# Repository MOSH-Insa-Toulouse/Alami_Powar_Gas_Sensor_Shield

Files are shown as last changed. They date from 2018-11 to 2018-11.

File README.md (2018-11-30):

**MOSH - Smart Devices – Arduino Gas Sensor Shield**

This project was completed as part of the &quot;Smart Devices&quot; Course of the Mastère spécialisé Innovative and secure IoT systems at INSA Toulouse.

**By :** _Amine Alami And Rameshwari Powar_

**Project Description**

- The aim of the project is to design an Arduino shield that incorporates a nanoparticle gas sensor and a RN2483 LoRa Module, which allows data from the gas sensor to be transmitted to a LoRa Gateway, through which it can be uploaded to the Cloud or a local network.
- The Arduino Gas Sensor Shield was designed using KiCad, a printed circuit board (PCB) design software package.
- The Shield can be used with Arduino UNO or other similar microcontroller kits, such as the Genuino 101.
- The Shield has a socket through which a RN2483-based LoRa Module could be plugged.

**CONTENT:**

**Design Files**

1. Schematic Diagram
2. PCB Footprint Layout
3. PCB 3D Layout

**Design Files**

1. **Schematic Diagram**

- Design Procedure

- We created a symbol for Operational Amplifier (LTC1050) and the RN2483 LoRa Module (RN2483\_Breakout) using KiCAD&#39;s symbol editor. We then assigned the footprint for the OpAmp and assigned an 8-pin socket as the footprint of the RN2483 LoRa Module.

- We drew the circuit diagram for the OpAmp Signal conditioning circuit (for impedance matching). The gas sensor was modelled as a resistor (RSensor1) in the circuit diagram. The footprint of the gas sensor was assigned to the TO-5-4 package (which is a casing in which the nanoparticle gas sensor will be put).

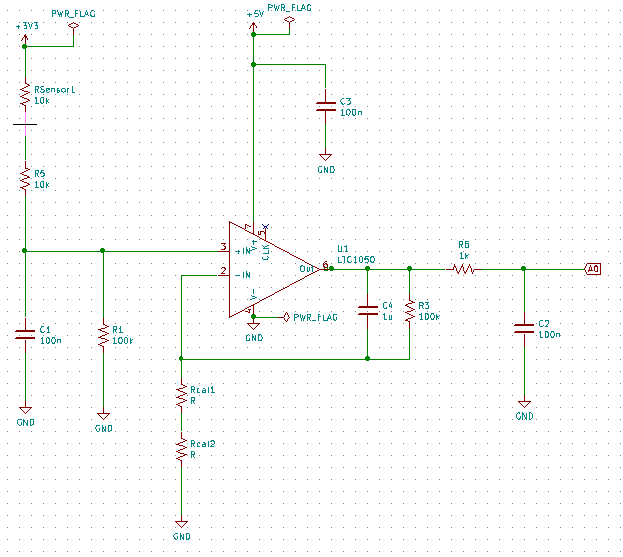
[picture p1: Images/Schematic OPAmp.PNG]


- The I/O of the Arduino Shield sockets were connected to the RN2483 LoRa Module and to the output of the impedance matching circuit.

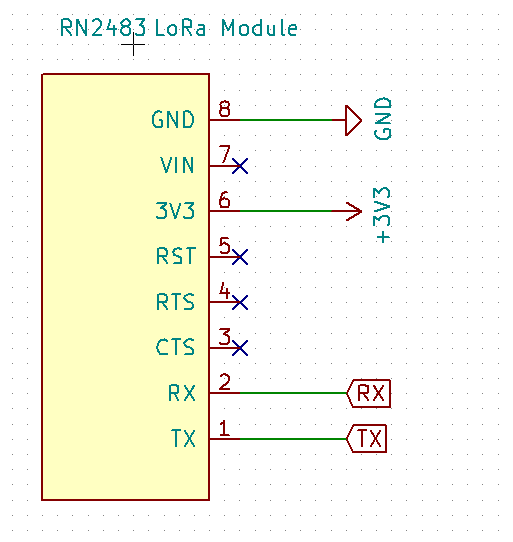
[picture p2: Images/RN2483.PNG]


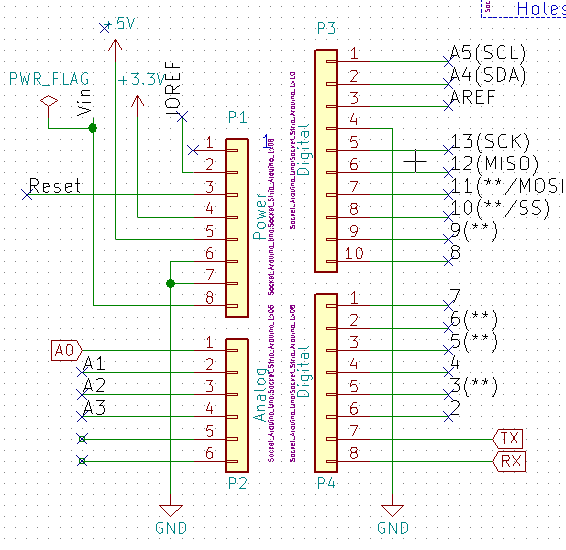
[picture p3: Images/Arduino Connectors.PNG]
 

- Schematic components

- The input resistor R1 - protects amplifier from electrostatic discharges.
- The capacitor C1 and the resistor R2 - filter the current noise.
- The capacitor C3 - filters the noise from the voltage input 5V.
- The resistor R4 – resistance at output of the amplifier.
- The resistor R5 and the capacitor C4 is a low-pass filter at the output of the assembly.
- The Rsensor1 - represents the gas sensor

1. **PCB Footprint Layout**

- Design Procedure

- Created a netlist from the schematic.
- Then we imported the components from the created netlist.
- We set design rules and set the track width of 0.8 mm and 1 mm for voltages
- We added a Ground Plane on the back
- Finally routed each components by wires

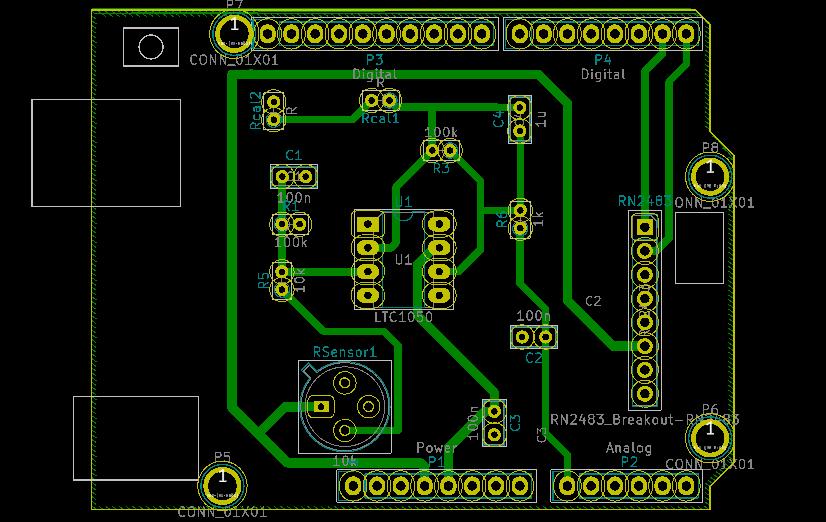
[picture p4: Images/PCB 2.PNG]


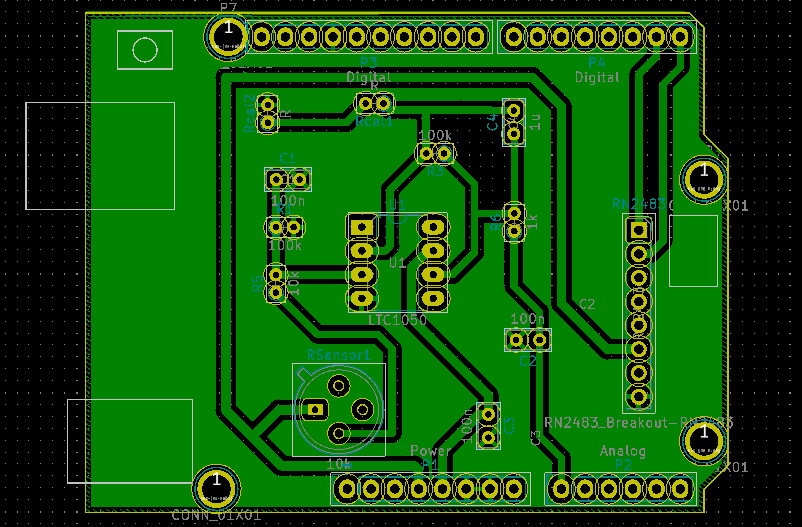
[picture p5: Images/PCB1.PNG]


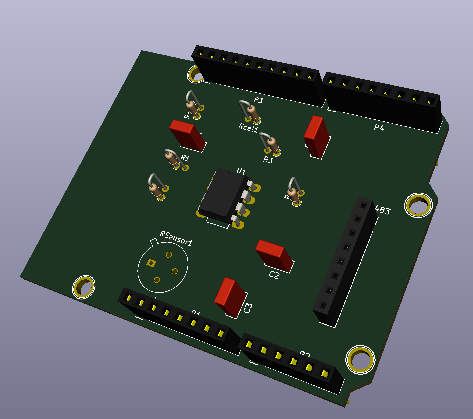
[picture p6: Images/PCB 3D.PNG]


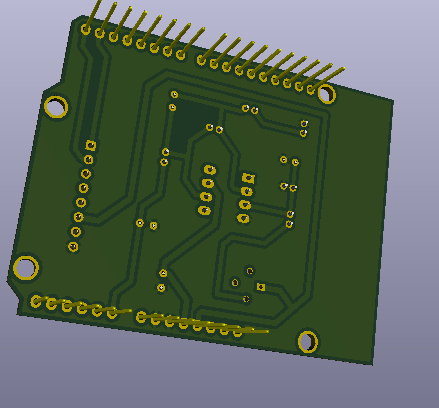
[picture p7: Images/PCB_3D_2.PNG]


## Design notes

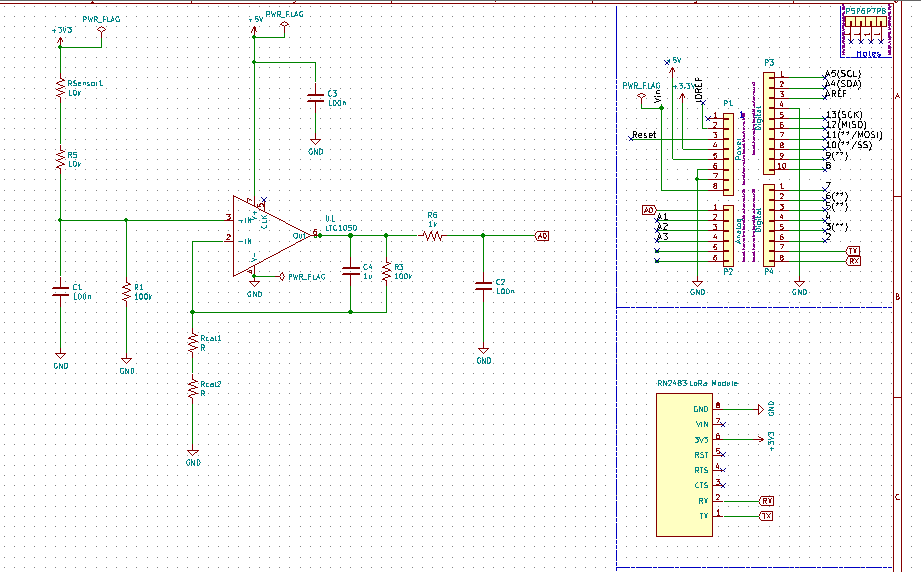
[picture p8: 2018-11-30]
Images/SchematicFull.PNG

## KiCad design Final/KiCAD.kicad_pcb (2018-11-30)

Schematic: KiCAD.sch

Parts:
C1, C2, C3: 100n; C_Rect_L4.6mm_W2.0mm_P2.50mm_MKS02_FKP02
C4: 1u; C_Rect_L4.6mm_W2.0mm_P2.50mm_MKS02_FKP02
P1: Power; Socket_Strip_Arduino_1x08
P2: Analog; Socket_Strip_Arduino_1x06
P3: Digital; Socket_Strip_Arduino_1x10
P4: Digital; Socket_Strip_Arduino_1x08
P5, P6, P7, P8: CONN_01X01; Arduino_1pin
R1, R3: 100k; R_Axial_DIN0204_L3.6mm_D1.6mm_P1.90mm_Vertical
R5: 10k; R_Axial_DIN0204_L3.6mm_D1.6mm_P1.90mm_Vertical
R6: 1k; R_Axial_DIN0204_L3.6mm_D1.6mm_P1.90mm_Vertical
RN2483: LoRa Module; PinSocket_1x08_P2.54mm_Vertical
RSensor1: 10k; TO-5-4
Rcal1, Rcal2: R; R_Axial_DIN0204_L3.6mm_D1.6mm_P1.90mm_Vertical
U1: LTC1050; DIP-8_W7.62mm_LongPads

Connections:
+3V3: P1.4, RN2483.6 (3V3), RSensor1.1
+5V: C3.1, P1.5, U1.7 (V+)
/2: P4.6
/3(**): P4.5
/4: P4.4
/5(**): P4.3
/6(**): P4.2
/7: P4.1
/8: P3.10
/9(**): P3.9
/10(**/SS): P3.8
/11(**/MOSI): P3.7
/12(MISO): P3.6
/13(SCK): P3.5
/A1: P2.2
/A2: P2.3
/A3: P2.4
/A4(SDA): P3.2
/A5(SCL): P3.1
/AREF: P3.3
/IOREF: P1.2
/Reset: P1.3
/Vin: P1.8
A0: C2.1, P2.1, R6.1
GND: C1.2, C2.2, C3.2, P1.6, P1.7, P3.4, R1.2, RN2483.8 (GND), Rcal2.2, U1.4 (V-)
unnamed: C1.1, R1.1, R5.2, U1.3 (+IN)
unnamed: C4.1, R3.1, R6.2, U1.6 (Out)
unnamed: C4.2, R3.2, Rcal1.1, U1.2 (-IN)
unnamed: R5.1, RSensor1.2
unnamed: Rcal1.2, Rcal2.1
RX: P4.8, RN2483.2 (RX)
TX: P4.7, RN2483.1 (TX)

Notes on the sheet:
Holes

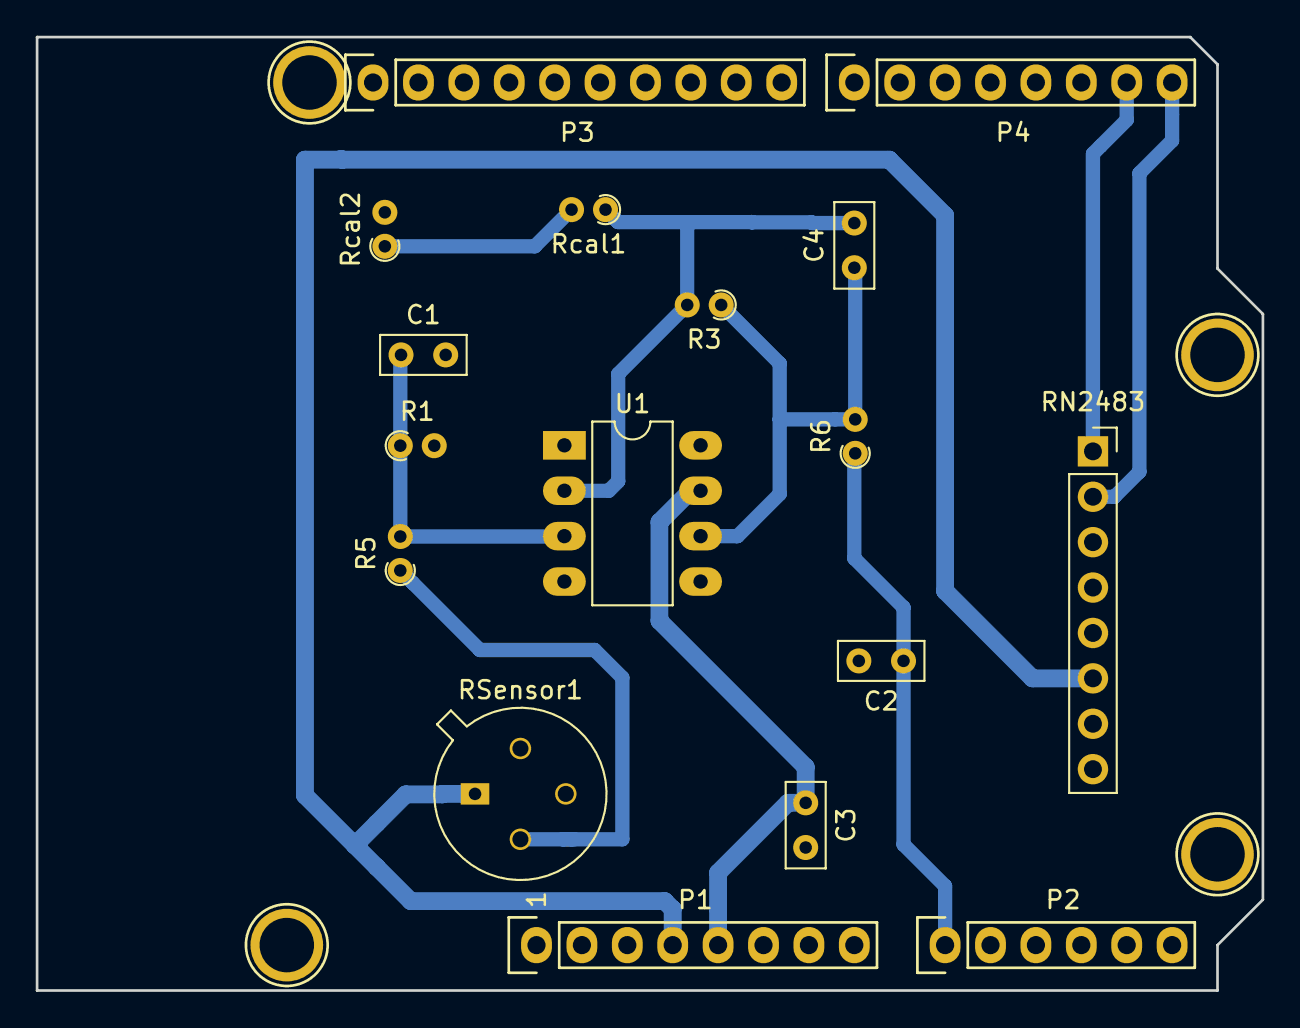
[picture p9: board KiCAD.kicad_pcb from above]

Board: 2 copper layers, 68.6 x 53.3 mm, 21 parts (0 on the bottom side), 11 nets.
